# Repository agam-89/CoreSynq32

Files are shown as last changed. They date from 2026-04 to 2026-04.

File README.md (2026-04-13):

# CoreSynq32

> Real-time 3-channel drum sequencer on ESP32 — FreeRTOS task architecture, 22050Hz PCM sample playback via onboard DAC, and live OLED grid display.

---

## Demo

CoreSynq32 Demo (https://www.youtube.com/watch?v=T27PNiOOfRY)

---

## Overview

CoreSynq32 is an 8-step programmable drum sequencer built on the ESP32. It plays back real WAV drum samples (kick, snare, hi-hat) through the ESP32's onboard DAC into an LM386 amplifier and speaker. Patterns are programmed live via tactile buttons and visualized on an SSD1306 OLED display.

The project is built around a concurrent FreeRTOS task architecture — sequencer timing, audio playback, and UI all run as independent tasks communicating via shared state and critical sections, rather than a single blocking loop.

---

## Features

- 3-channel step sequencer — Kick, Snare, Hi-Hat
- 8-step grid with page toggle (Steps 1–4 / Steps 5–8)
- Real WAV sample playback at 22050Hz via ESP32 DAC
- Hardware timer ISR drives sample-accurate PCM output
- Live OLED display — scrolling playhead, active steps, BPM, track info
- BPM control via potentiometer (60–240 BPM)
- Play/Stop, Track Select, Page Toggle, and Clear controls

---

## Hardware

| Component | Details |
|---|---|
| ESP32 DevKit V1 | Main microcontroller |
| SSD1306 OLED | 128×64, I2C |
| Tactile push buttons | ×4 step + ×4 control |
| Potentiometer | BPM control, GPIO 34 |
| LM386 amplifier | Audio output stage |
| Speaker | Salvaged desktop speaker |

Amplifier circuit schematic (LM386 + coupling caps) is included in `/schematics`.

---

## Pin Map

| GPIO | Function |
|---|---|
| 13, 12, 14, 27, 26, 33, 32, 15 | Step buttons 1–8 |
| 4 | Track select |
| 5 | Page toggle |
| 6 | Play / Stop |
| 7 | Clear current track |
| 34 | BPM potentiometer |
| 21 | OLED SDA |
| 22 | OLED SCL |
| 25 | DAC audio output |

---

## Controls

| Button | Action |
|---|---|
| STEP 1–4 | Toggle steps on current page |
| Track Select | Cycle between KICK → SNARE → HAT |
| Page Toggle | Switch between steps 1–4 (PG:A) and 5–8 (PG:B) |
| Play/Stop | Start or pause sequencer |
| Clear | Erase all steps on current track |
| Potentiometer | Adjust BPM live (60–240) |

---

## Architecture

```
┌─────────────┐   shared state    ┌──────────────────┐
│  vUI Task   │ ────────────────▶ │  vSequencer Task │
│  (Core 0)   │                   │  (Core 1)        │
│             │                   │                  │
│ Button scan │                   │ Advances playhead│
│ BPM read    │                   │ Calls triggerSound│
│ OLED draw   │                   └────────┬─────────┘
└─────────────┘                            │
                                           ▼
                                 ┌──────────────────┐
                                 │  Timer ISR       │
                                 │  @ 22050 Hz      │
                                 │                  │
                                 │ Feeds DAC one    │
                                 │ sample at a time │
                                 │ Mixes 3 channels │
                                 └──────────────────┘
```

- `vSequencer` runs on Core 1 at highest priority — handles beat timing
- `vUI` runs on Core 0 — handles display refresh and button scanning
- Hardware timer ISR fires at 22050Hz independent of both tasks
- 3-channel mixer averages active samples to prevent DAC clipping
- Shared state protected with `portENTER_CRITICAL` / `portEXIT_CRITICAL`

---

## Audio Pipeline

```
WAV files → Audacity (8-bit unsigned, mono, 22050Hz) → Python → C byte arrays → samples.h
ESP32 Flash → Timer ISR → dacWrite(GPIO 25) → LM386 → 1000µF cap → Speaker
```

---

## Software

- **IDE:** Arduino IDE 2.x
- **Core:** ESP32 Arduino Core 3.x
- **Libraries:** Adafruit SSD1306, Adafruit GFX, FreeRTOS (built-in)

---

## Custom Samples

`samples.h` is generated from your own WAV files using the script in `/tools/wav_to_c.py`. To swap in your own drum sounds:

1. Export your WAV files from Audacity as **8-bit unsigned PCM, mono, 22050Hz**
2. Place them in the same folder as `wav_to_c.py`
3. Update the filenames in the script and run it:
```
python wav_to_c.py
```
4. Paste the output into `samples.h`, replacing the existing arrays

Any short one-shot drum sample works — keep them under 1 second to avoid flash memory issues.

---

## Repository Structure

```
CoreSynq32/
├── drum_mchn/
│   ├── drum_mchn.ino       # Main source
│   └── samples.h           # WAV sample arrays (kick, snare, hihat)
├── schematics/
│   ├── wokwi_diagram.png   # Full system schematic (ESP32 + OLED + buttons)
│   └── 386amp.kicad_sch    # LM386 amplifier circuit
├── tools/
│   └── wav_to_c.py         # Converts WAV files to C byte arrays for samples.h
├── demo/
│   └── drum_machine_demo.mp4
└── README.md
```

---

## Resume Keywords

FreeRTOS · Real-time task scheduling · Inter-task synchronization · Hardware timer ISR · PCM audio · DAC · I2C · ESP32 · Embedded C · KiCad

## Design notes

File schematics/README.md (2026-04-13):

# schematics

Circuit diagrams for CoreSynq32.

## Files

**`wokwi_diagram.png`** — Full system schematic covering the digital side: ESP32, SSD1306 OLED, 8 step buttons, 4 control buttons, and BPM potentiometer. Created in Wokwi.

**`386amp.kicad_sch`** — Analog audio output stage. ESP32 DAC (GPIO 25) → LM386 amplifier → 1000µF output cap → speaker. Designed in KiCad.

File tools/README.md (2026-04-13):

# tools

Utility scripts for CoreSynq32.

## wav_to_c.py

Converts WAV drum samples into C byte arrays for use in `samples.h`.

### Usage

```
python wav_to_c.py
```

### Requirements

- Python 3.x
- WAV files exported from Audacity as **8-bit unsigned PCM, mono, 22050Hz**

### Output

Prints C declarations for all 3 samples directly to terminal:

```c
const uint8_t kick[] = {128, 145, ...};
const int kick_len = 5978;

const uint8_t snare[] = {128, 130, ...};
const int snare_len = 3658;

const uint8_t hihat[] = {128, 132, ...};
const int hihat_len = 3978;
```

Copy the output and paste it into `drum_mchn/samples.h` between the `#ifndef` and `#endif` guards.

### Changing Sample Files

Edit the filenames at the top of the script to match your WAV files:

```python
files = ["your-kick.wav", "your-snare.wav", "your-hihat.wav"]
names = ["kick", "snare", "hihat"]
```

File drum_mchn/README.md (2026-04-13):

# drum_mchn

Main firmware for CoreSynq32.

## Files

**`drum_mchn.ino`** — Main source. Contains FreeRTOS task definitions, audio engine, sequencer logic, and OLED UI.

**`samples.h`** — PCM sample arrays for kick, snare, and hi-hat. Generated from WAV files using `/tools/wav_to_c.py`. Not included in the repo — generate your own using the instructions in the root README.

## Dependencies

Install via Arduino IDE Library Manager:
- `Adafruit SSD1306`
- `Adafruit GFX Library`

FreeRTOS is built into the ESP32 Arduino core, no separate install needed.

## Board Setup

- Board: `ESP32 Dev Module`
- Core: ESP32 Arduino Core 3.x
- Flash size: 4MB
- Partition scheme: Default

## Notes

- `samples.h` must be present in this folder before compiling — the sketch won't build without it
- Timer is configured for 22050Hz sample rate — matches the WAV export settings in `/tools`
- DAC output is on GPIO 25 — connect to LM386 amp circuit (see `/schematics`)

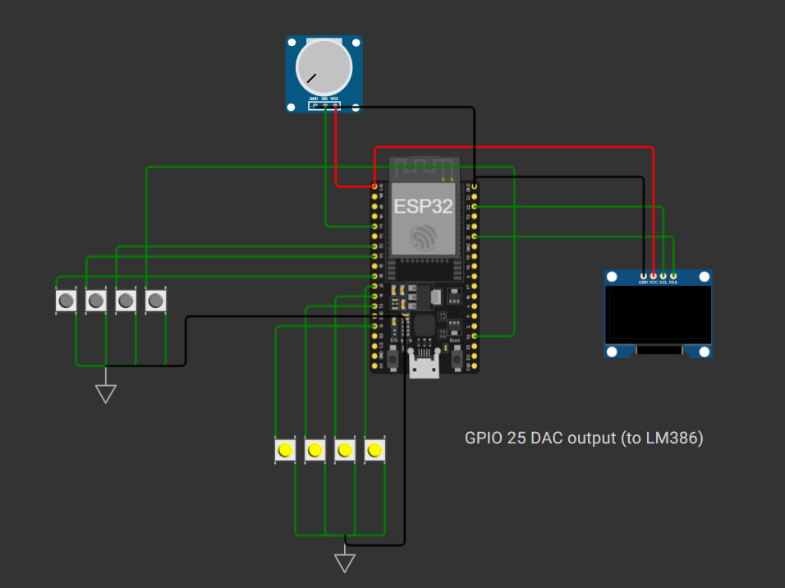
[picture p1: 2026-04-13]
schematics/wokwi_diagram.png

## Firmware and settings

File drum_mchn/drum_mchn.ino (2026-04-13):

#include <Arduino.h>
#include <Wire.h>
#include <Adafruit_GFX.h>
#include <Adafruit_SSD1306.h>
#include "samples.h" 

#define SCREEN_WIDTH 128
#define SCREEN_HEIGHT 64
Adafruit_SSD1306 display(SCREEN_WIDTH, SCREEN_HEIGHT, &Wire, -1);

const int btnPins[8] = {13, 12, 14, 27, 26, 33, 32, 15};
const int potPin = 34;
const int dacPin = 25;

bool patterns[3][8] = {0}; 
int currentTrack = 0; 
int currentStep = 0;
int currentPage = 0;  
int bpm = 120;
bool isPlaying = true;

// --- PCM Sample Player Engine ---
const uint8_t* sampleData[3] = {kick, snare, hihat};
const int sampleLens[3] = {kick_len, snare_len, hihat_len};

volatile int audioPos[3] = {-1, -1, -1};
volatile bool audioActive[3] = {false, false, false};

hw_timer_t* sampleTimer = NULL;
portMUX_TYPE timerMux = portMUX_INITIALIZER_UNLOCKED;

void IRAM_ATTR onSampleTimer() {
  portENTER_CRITICAL_ISR(&timerMux);
  int32_t mixed = 0; 
  int activeCount = 0;
  for (int i = 0; i < 3; i++) {
    if (audioActive[i]) {
      int16_t sample = (int16_t)sampleData[i][audioPos[i]] - 128;
      mixed += sample;
      activeCount++;
      audioPos[i]++;
      if (audioPos[i] >= sampleLens[i]) {
        audioPos[i] = -1;
        audioActive[i] = false;
      }
    }
  }
  if (activeCount > 0) {
    int32_t finalOut = mixed + 128;
    if (finalOut > 255) finalOut = 255;
    if (finalOut < 0) finalOut = 0;
    dacWrite(dacPin, (uint8_t)finalOut);
  } else {
    dacWrite(dacPin, 128); 
  }
  portEXIT_CRITICAL_ISR(&timerMux);
}

void triggerSound(int track) {
  portENTER_CRITICAL(&timerMux);
  audioPos[track] = 0;
  audioActive[track] = true;
  portEXIT_CRITICAL(&timerMux);
}

void vSequencer(void *pvParameters) {
  for (;;) {
    if (isPlaying) {
      for (int i = 0; i < 3; i++) {
        if (patterns[i][currentStep]) triggerSound(i);
      }
      currentStep = (currentStep + 1) % 8;
    }
    vTaskDelay(pdMS_TO_TICKS((60000 / bpm) / 4));
  }
}

void vUI(void *pvParameters) {
  for (;;) {
    bpm = map(analogRead(potPin), 0, 4095, 60, 240);
    for (int i = 0; i < 8; i++) {
      if (digitalRead(btnPins[i]) == LOW) {
        if (i < 4) {
          int stepIndex = i + (currentPage * 4);
          patterns[currentTrack][stepIndex] = !patterns[currentTrack][stepIndex];
        }
        else if (i == 4) currentTrack = (currentTrack + 1) % 3;
        else if (i == 5) currentPage = !currentPage;
        else if (i == 6) isPlaying = !isPlaying;
        else if (i == 7) memset(patterns[currentTrack], 0, 8);
        vTaskDelay(pdMS_TO_TICKS(200)); 
      }
    }
    
    display.clearDisplay();
    display.setTextColor(SSD1306_WHITE);
    display.setTextSize(1);

    // --- Header ---
    display.setCursor(0, 0);
    display.printf("TRK:%s", (currentTrack == 0 ? "KICK" : (currentTrack == 1 ? "SNARE" : "HAT")));
    
    display.setCursor(100, 0);
    display.print(currentPage == 0 ? "P:1" : "P:2");

    // --- Editing Bar ---
    int highlightX = currentPage * 64;
    display.drawFastHLine(highlightX + 4, 21, 56, SSD1306_WHITE);
    display.setCursor(highlightX + 12, 12);
    display.print("EDITING");

    // --- Sequencer Steps ---
    for(int s=0; s<8; s++) {
      int xPos = s * 16 + 2;
      display.drawRect(xPos, 25, 12, 12, 1);
      if(patterns[currentTrack][s]) display.fillRect(xPos + 2, 27, 8, 8, 1);
      if(currentStep == s && isPlaying) {
        display.fillTriangle(xPos + 2, 45, xPos + 10, 45, xPos + 6, 40, 1);
      }
    }

    // --- Footer ---
    display.setCursor(0, 56);
    display.printf("BPM:%d", bpm);
    
    display.setCursor(75, 56);
    display.print(isPlaying ? "> PLAYING" : "|| PAUSED");

    display.display();
    vTaskDelay(pdMS_TO_TICKS(50));
  }
}

void setup() {
  if(!display.begin(SSD1306_SWITCHCAPVCC, 0x3C)) for(;;);
  for (int i = 0; i < 8; i++) pinMode(btnPins[i], INPUT_PULLUP);
  pinMode(dacPin, OUTPUT);
  dacWrite(dacPin, 128);

  sampleTimer = timerBegin(1000000); 
  timerAttachInterrupt(sampleTimer, &onSampleTimer);
  timerAlarm(sampleTimer, 45, true, 0); 

  xTaskCreatePinnedToCore(vSequencer, "Seq", 5000, NULL, 3, NULL, 1);
  xTaskCreatePinnedToCore(vUI,        "UI",  4000, NULL, 1, NULL, 0);
}

void loop() {}
